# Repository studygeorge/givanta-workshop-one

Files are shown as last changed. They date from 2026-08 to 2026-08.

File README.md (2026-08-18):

# WORKSHOP ONE — верстак инженера

**GIVANTA MASTERS** · мебель для тех, кто делает вещи руками

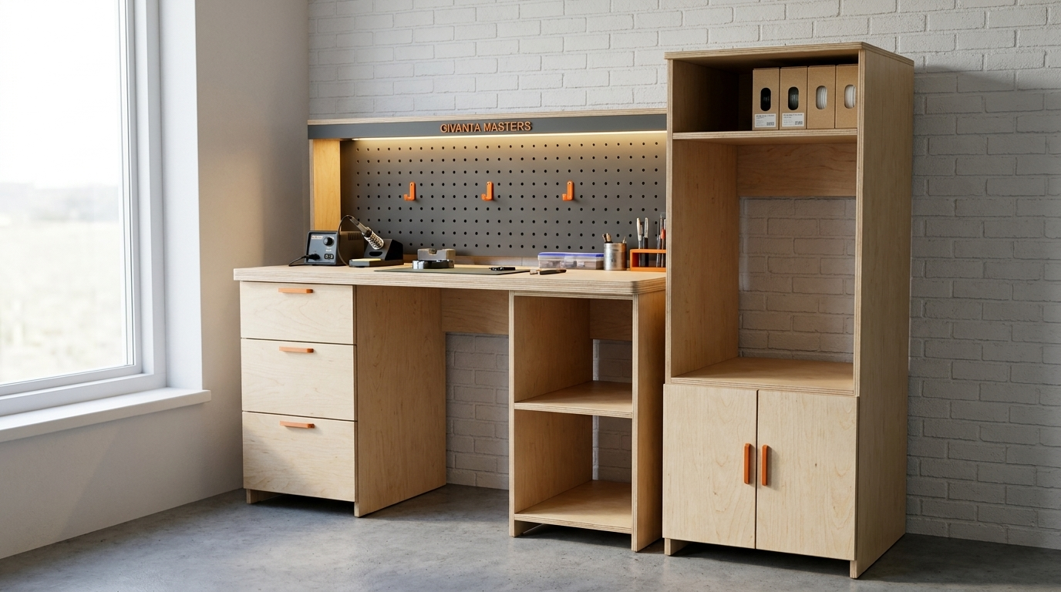
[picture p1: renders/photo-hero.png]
WORKSHOP ONE


Рабочее место для инженера-мейкера, который **паяет, печатает на 3D-принтере,
красит и собирает**. Два независимых модуля из берёзовой фанеры 18 мм:
верстак с надстройкой и башня под 3D-принтер. Спроектировано в Fusion 360,
все детали — прямоугольный раскрой, собирается на конфирматы без станков с ЧПУ.

---

## Зоны

| Зона | Где | Что предусмотрено |
|---|---|---|
| Пайка | столешница под надстройкой | перфопанель под инструмент, полка под паяльную станцию и БП, экран под LED-подсветку рабочей зоны |
| Сборка | столешница 1600×650 | двойная плита 36 мм — не гуляет под ударами и струбцинами, вынос 50 мм спереди под струбцины |
| Покраска и расходники | открытая тумба справа | полка под краски, грунты и боксы; всё на расстоянии вытянутой руки |
| Мелочёвка и инструмент | тумба слева | три ящика: метизы, инструмент, электроника |
| 3D-печать | башня | площадка на высоте 596 мм под принтер до 614 мм шириной (Creality K2 встаёт), закрытый склад филамента снизу, полка сверху |

## Визуализации

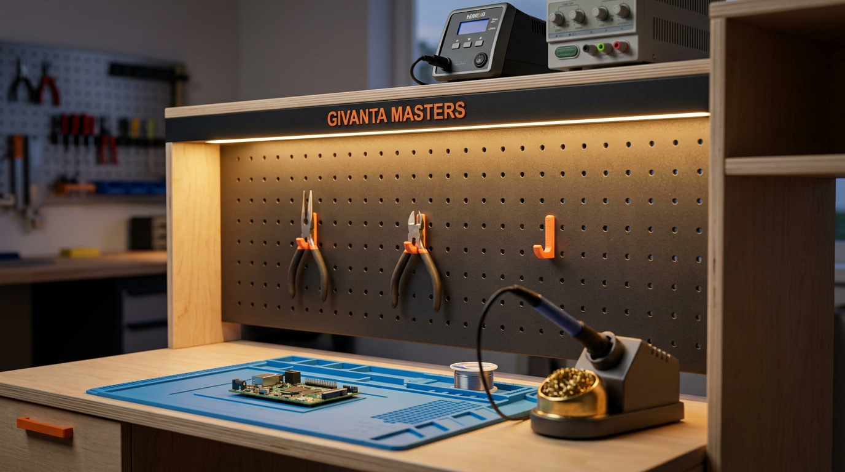
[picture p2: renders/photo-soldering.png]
Зона пайки


| | |
|---|---|
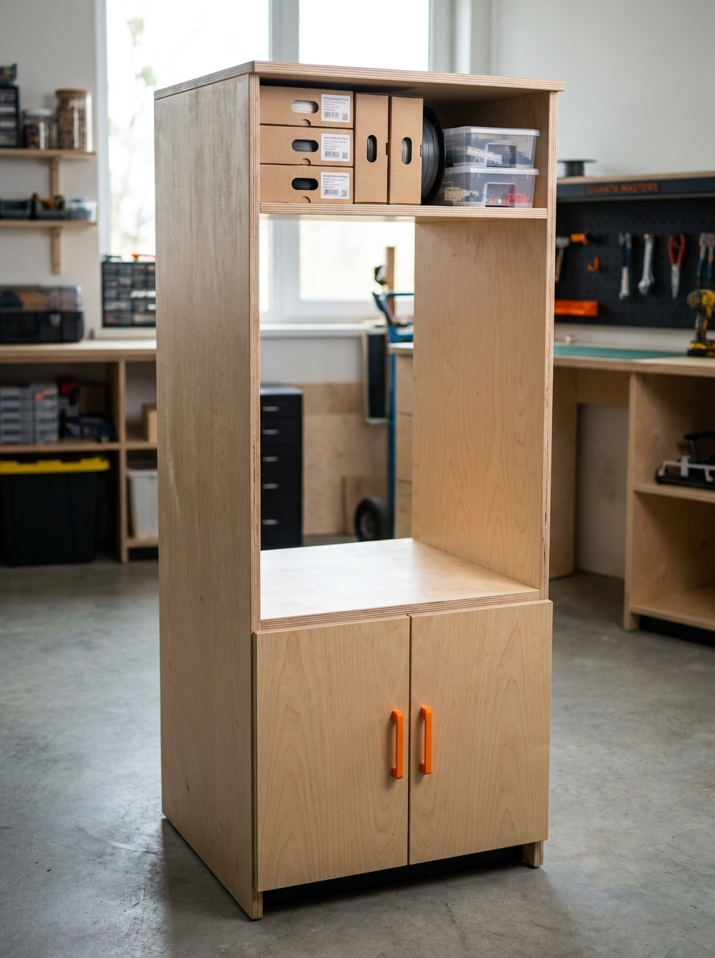
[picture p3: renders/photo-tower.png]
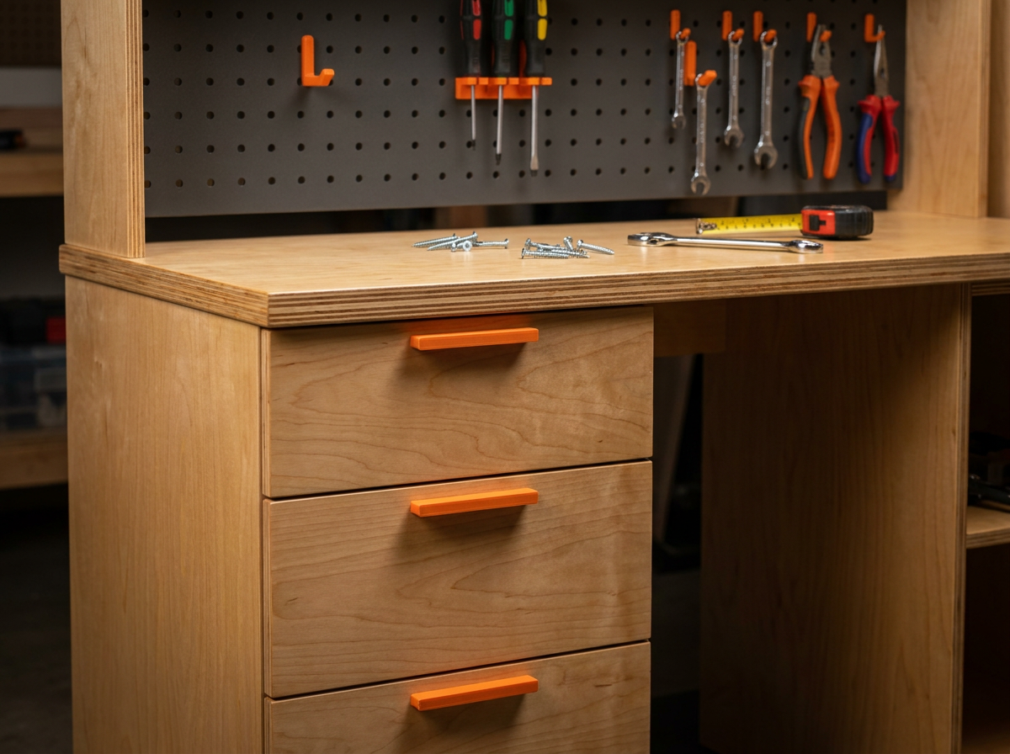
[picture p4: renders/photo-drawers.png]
Ящики
|  |  |

## Чертежи

Размеры в мм. Исходники — SVG в [docs/drawings](docs/drawings).

Чертёж верстака

Чертёж башни

Печатные детали

## Модель в Fusion 360

| | |
|---|---|
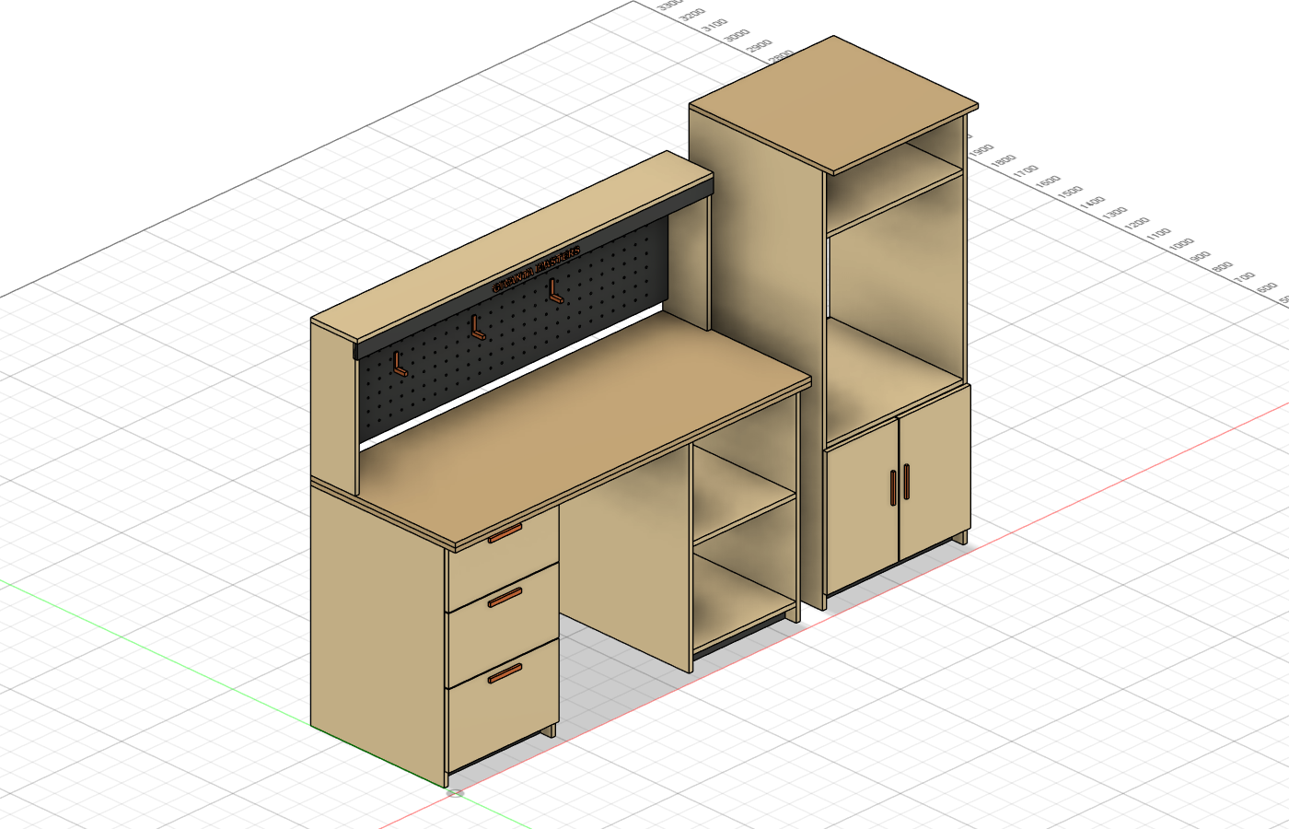
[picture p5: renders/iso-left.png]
Изометрия
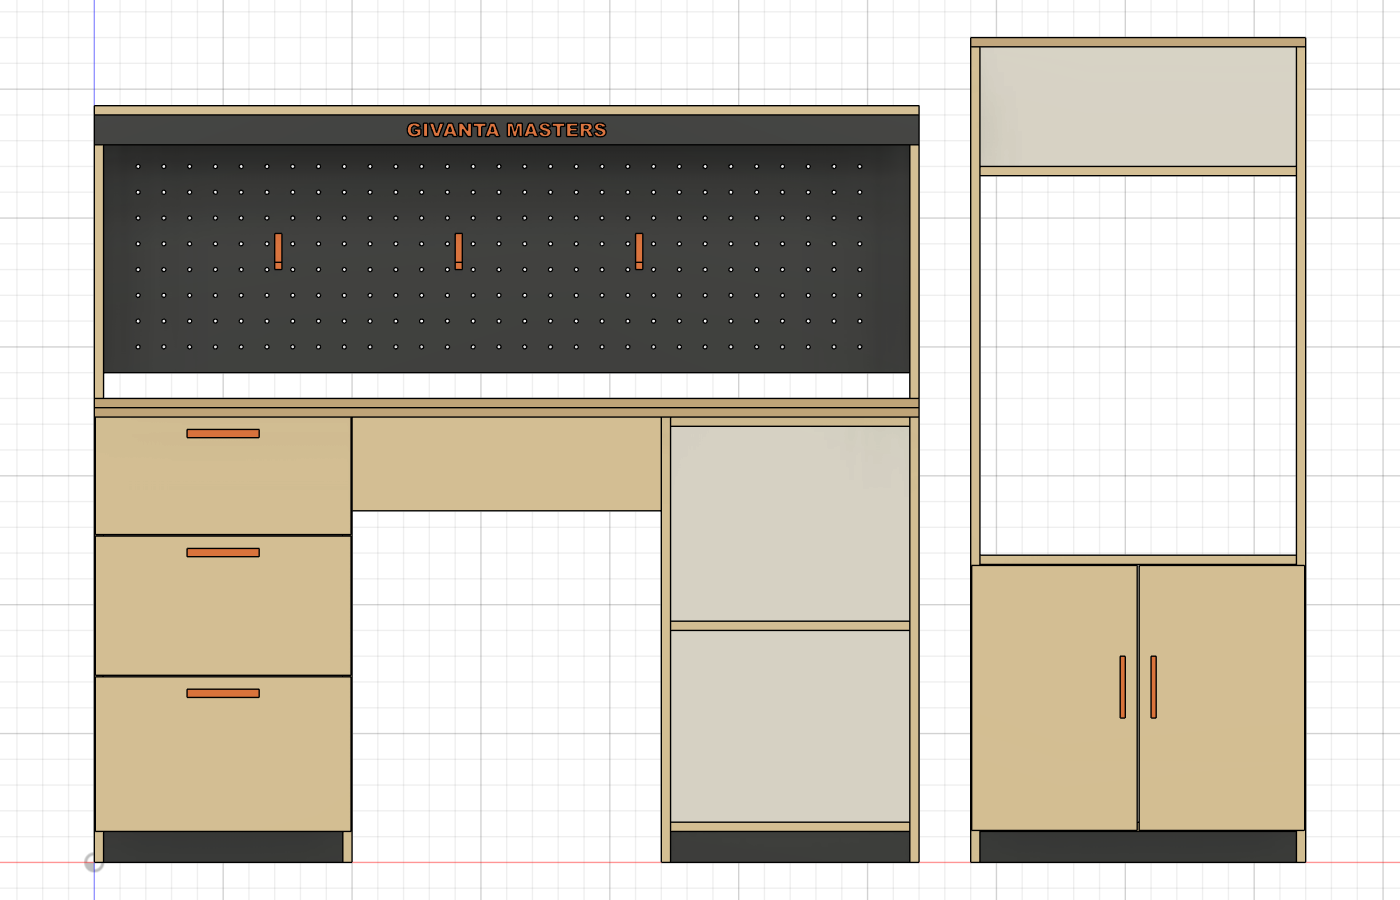
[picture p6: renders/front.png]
Фронт
|  |  |
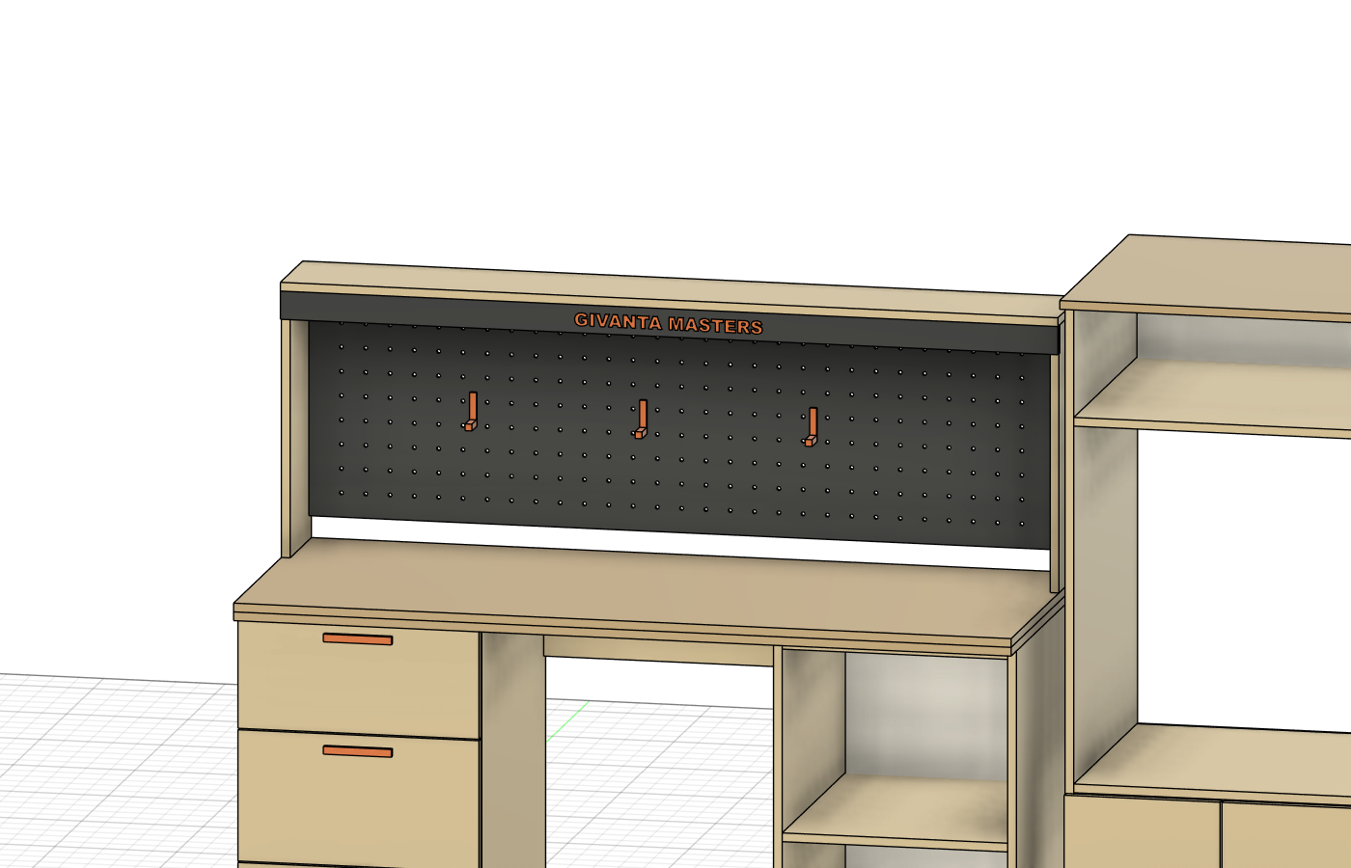
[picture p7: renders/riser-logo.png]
Надстройка
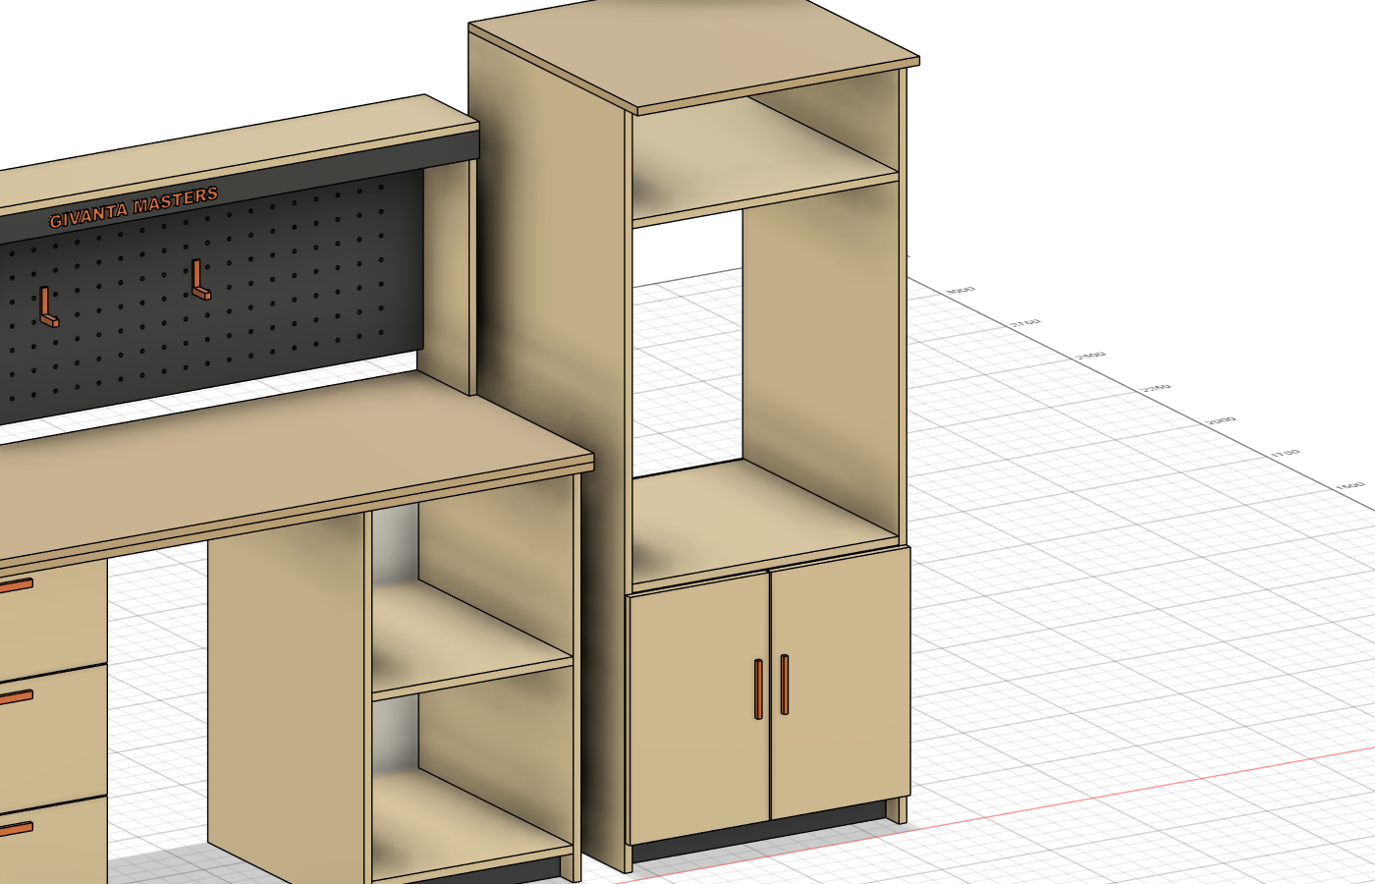
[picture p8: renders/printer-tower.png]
|  |  |

## Габариты

- **Верстак**: 1600 × 650 мм, столешница на высоте 900 мм, с надстройкой — 1468 мм
- **Проём для ног**: 600 мм — можно работать сидя
- **Башня**: 650 × 650 × 1600 мм; проём под принтер 614 × 736 мм (Ш×В)
- Перфопанель: шаг отверстий 50 мм, Ø8 мм — под печатные крючки из комплекта

## Материалы

| Материал | Расход |
|---|---|
| Фанера берёза 18 мм, шлифованная | ~9,2 м² → 5 листов 1525×1525 (с запасом на раскрой) |
| ХДФ 6 мм (задники) + перфо-ХДФ | ~2 м² → 1 лист |
| PETG для печатных деталей | ~150 г |
| Конфирматы 7×50, шканты 8×40, петли накладные (2 шт), направляющие ящиков 550 мм (3 пары) | по месту |
| LED-лента 12 В тёплая + блок питания | 1,5 м под полкой надстройки |

Полная **карта раскроя**: [docs/cutlist.csv](docs/cutlist.csv) — 25 позиций,
все детали прямоугольные, парные детали учтены количеством.

## Печатные детали (PETG)

| Файл | Деталь | Кол-во |
|---|---|---|
| [print/drawer-pull-140mm.stl](print/drawer-pull-140mm.stl) | ручка ящика 140 мм | 3 |
| [print/door-pull-120mm.stl](print/door-pull-120mm.stl) | ручка двери 120 мм | 2 |
| [print/pegboard-hook-40mm.stl](print/pegboard-hook-40mm.stl) | крючок перфопанели, вылет 40 мм | 6+ |

Печатать PETG (ручки держат нагрузку и не боятся растворителей), плашмя,
без поддержек, заполнение 40 %.

## Сборка — порядок

1. **Тумбы верстака**: бока + дно + царги на конфирматы, цоколь, задник в паз
   или на гвозди. Левая тумба — установить направляющие до сборки короба.
2. **Столешница**: склеить два слоя 18 мм (ПВА + саморезы снизу через царги),
   положить на тумбы, закрепить через царги. Между тумбами — задняя связь.
3. **Надстройка**: щёки на столешницу (шканты + уголки к стене или столешнице),
   перфопанель между щеками, сверху полка и LED-экран. Лента клеится за экран.
4. **Ящики**: короба из фанеры 12–15 мм по внутренним размерам направляющих,
   фасады навесить с зазором 3 мм.
5. **Башня**: бока + дно + площадка + верхняя полка + крыша, задники, двери на
   накладные петли. Принтер ставить на резиновые ножки, филамент — вниз,
   в закрытый отсек (туда же силикагель).
6. Кромки — шлифовка P120→P240, масло-воск или полиуретановый лак в 2 слоя.

## CAD

- [cad/workshop-one-full.step](cad/workshop-one-full.step) — полная сборка (STEP)
- Модель построена скриптом через Fusion 360 API — все размеры параметрические

## Серия GIVANTA MASTERS

- [BINSTACK](https://github.com/studygeorge/givanta-binstack) — настольный органайзер электронщика (фанера + версия для 3D-печати)

## Лицензия

CC BY 4.0 — стройте, дорабатывайте, делитесь. Указывайте авторство:
**GIVANTA MASTERS**.

---

*GIVANTA MASTERS · 2026*

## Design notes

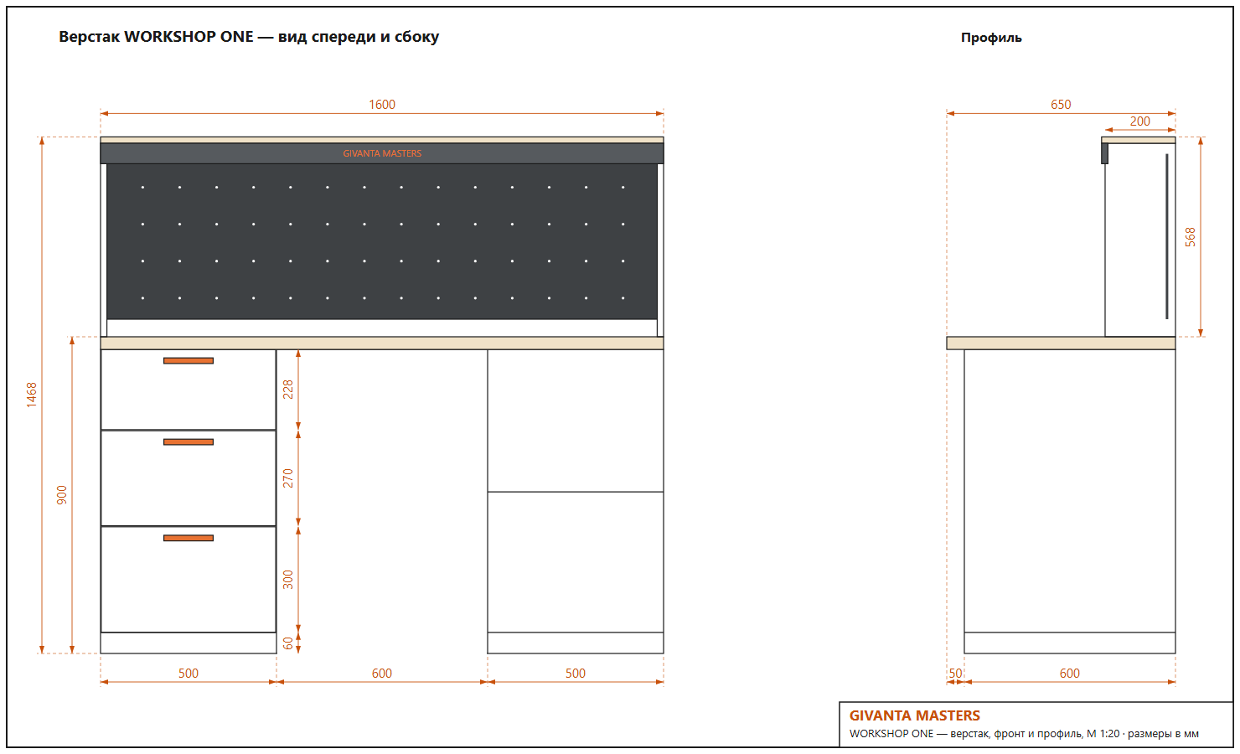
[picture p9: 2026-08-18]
docs/drawings/workbench.png

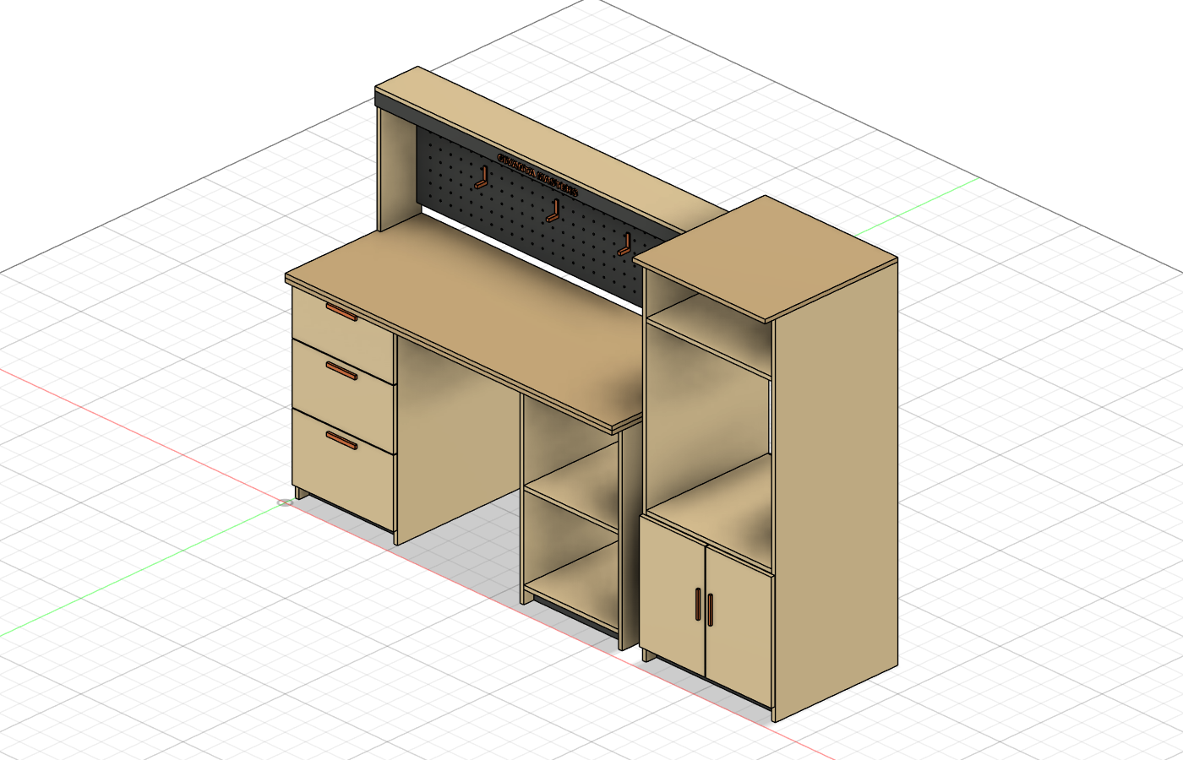
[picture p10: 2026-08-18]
renders/hero.png

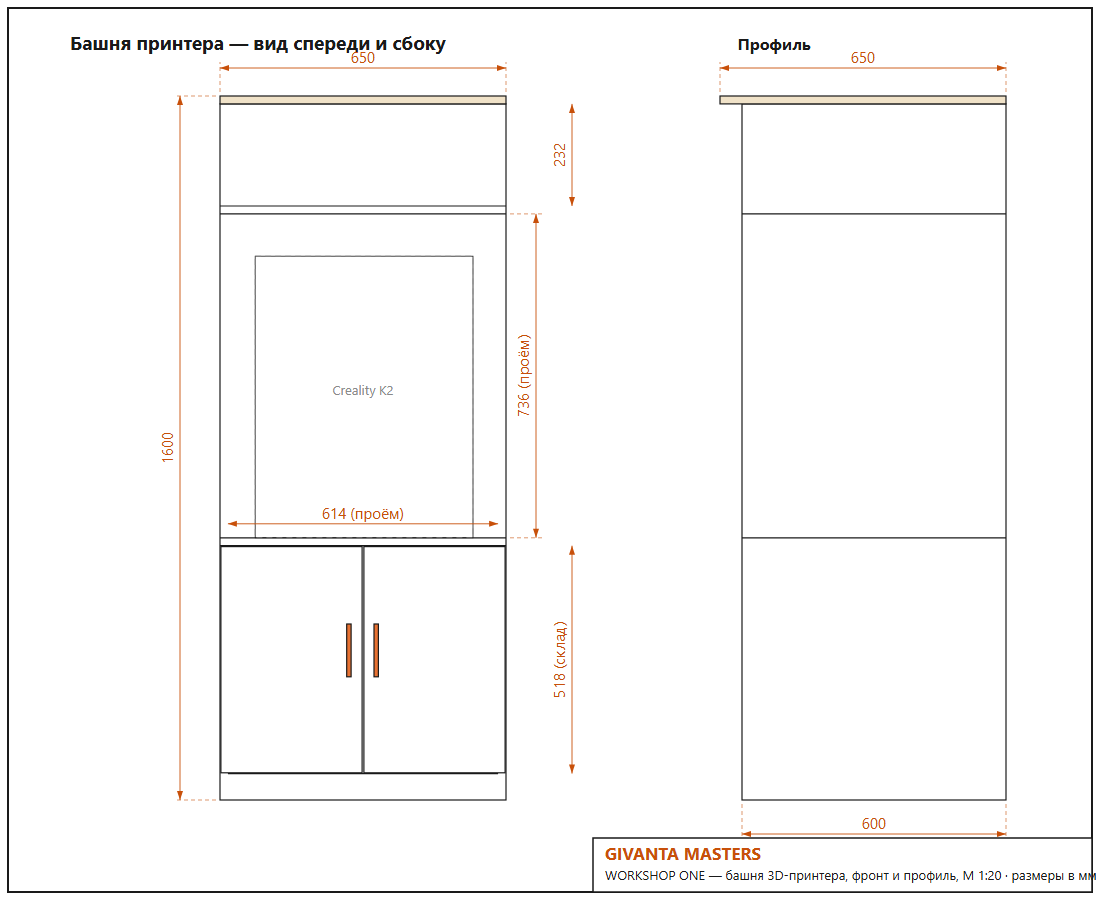
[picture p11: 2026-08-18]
docs/drawings/tower.png

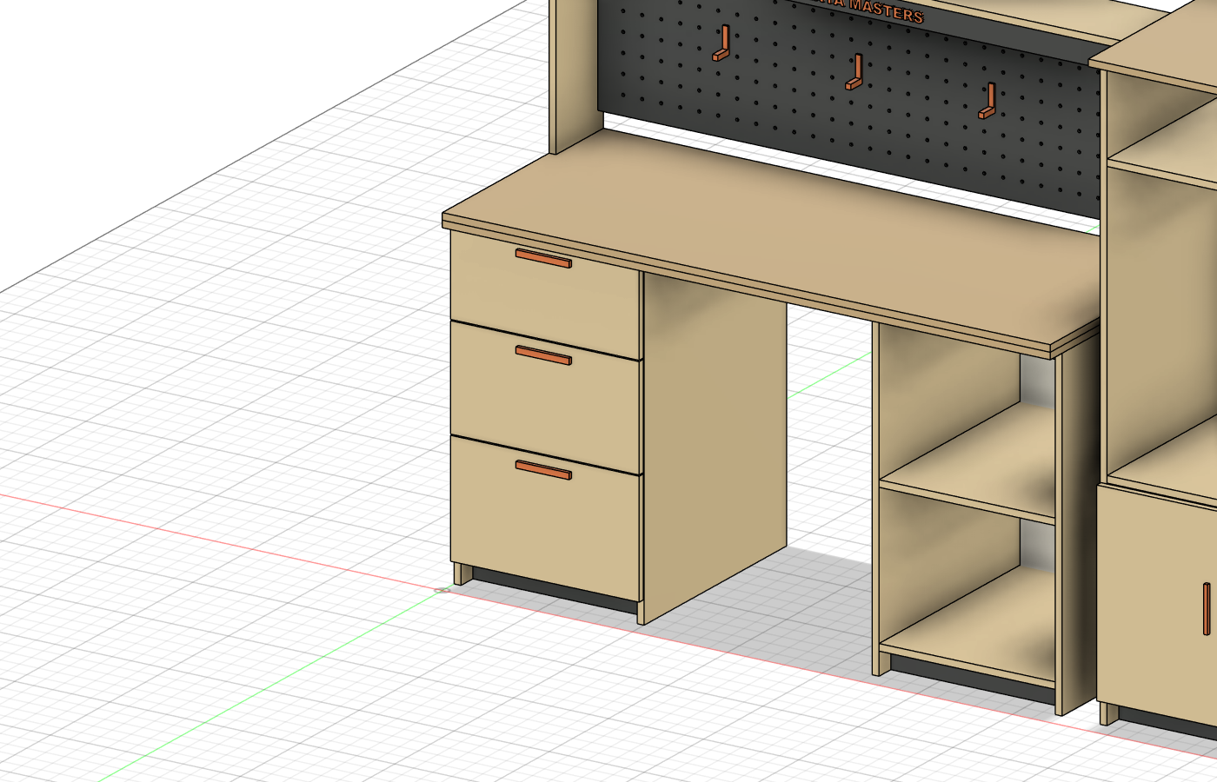
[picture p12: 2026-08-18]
renders/drawers.png

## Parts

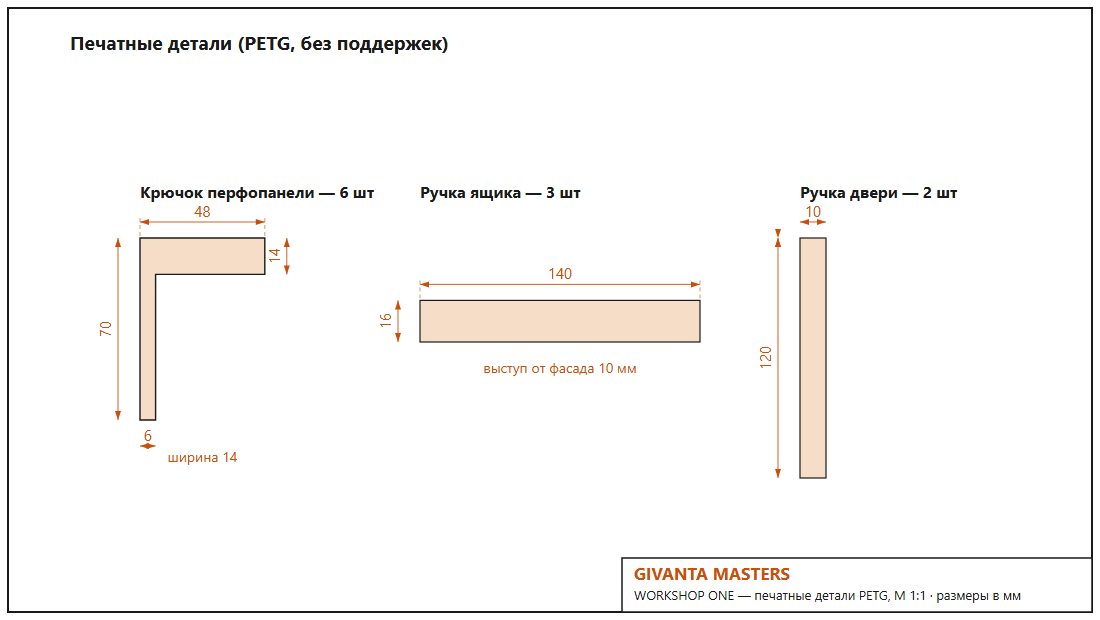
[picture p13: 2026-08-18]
docs/drawings/printed-parts.png

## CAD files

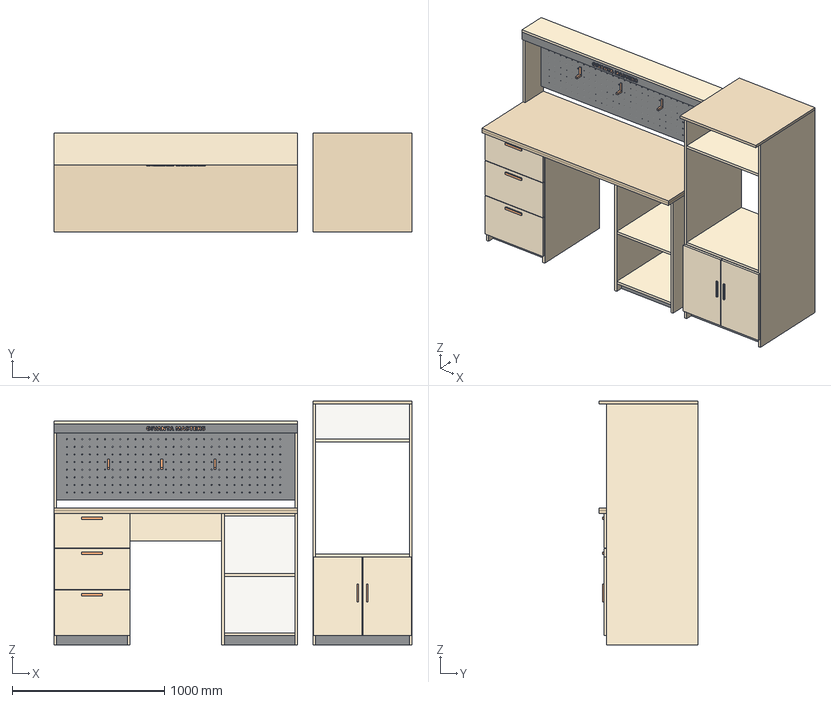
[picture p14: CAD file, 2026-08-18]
cad/workshop-one-full.step
2350.0 x 650.0 x 1600.0 mm

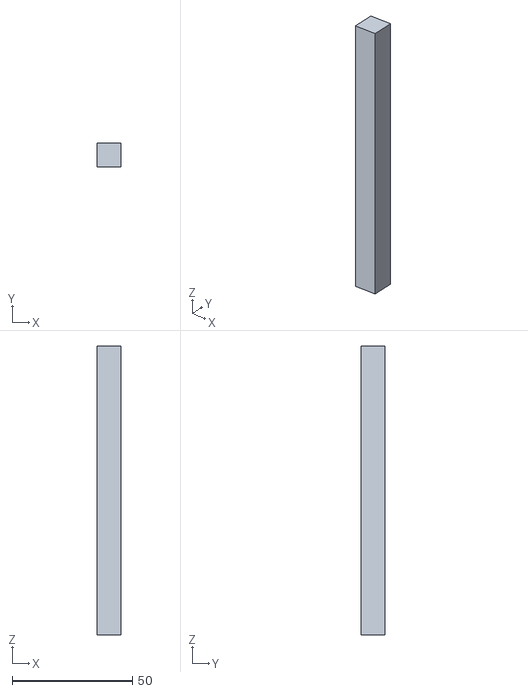
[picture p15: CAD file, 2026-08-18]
print/door-pull-120mm.stl
10.0 x 10.0 x 120.0

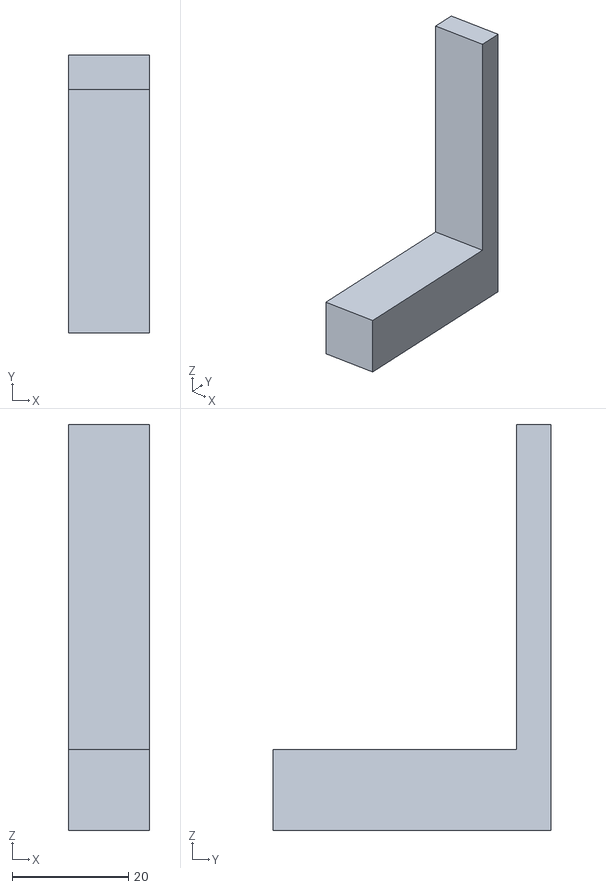
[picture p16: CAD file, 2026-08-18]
print/pegboard-hook-40mm.stl
14.0 x 48.0 x 70.0

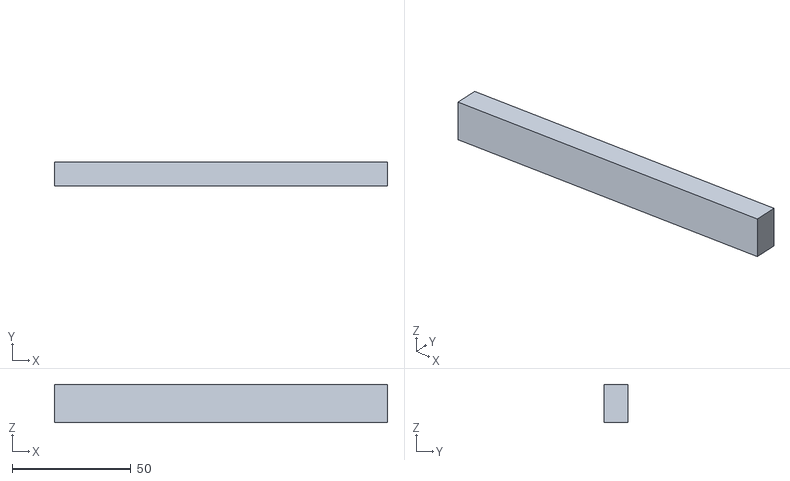
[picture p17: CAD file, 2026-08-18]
print/drawer-pull-140mm.stl
140.0 x 10.0 x 16.0

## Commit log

2026-08-18 WORKSHOP ONE: верстак инженера + башня 3D-принтера
    Фанера 18 мм, два модуля: верстак 1600x650x900 с надстройкой-перфопанелью
    и башня 650x650x1600 под Creality K2. Рендеры, STEP, STL печатных деталей,
    карта раскроя. Спроектировано в Fusion 360 через API.
    [cutlist.csv, door-pull-120mm.stl, drawer-pull-140mm.stl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]
2026-08-18 Фотореалистичные визуализации, чертежи с размерами (SVG+PNG)
    - 4 фото-рендера по референсам модели (hero, зона пайки, башня, ящики)
    - Чертежи: верстак, башня, печатные детали — размерные линии, штамп GIVANTA MASTERS
    - README: новый hero, разделы «Визуализации» и «Чертежи»
2026-08-18 Фикс: hero и башня без принтера, LICENSE без тире, ссылка на BINSTACK
